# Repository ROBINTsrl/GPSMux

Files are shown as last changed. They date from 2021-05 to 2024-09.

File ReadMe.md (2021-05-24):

# GPSMux

This board and related firmware can be used to switch between two serial NMEA GPS feed based on fix status.
The resulting feed is transmitted over a third serial line with RS232 levels.
The board is designed around [Cypress](https://www.cypress.com/) PSoC CY8C27143.

PCB has been designed with [KiCAD](https://www.kicad.org/).

## Firmware

The project firmware requires Cypress [PSoC Designer 5.4](https://www.cypress.com/documentation/software-and-drivers/psoc-designer-54-sp1) to be compiled.

#

Live long and prosper!

That's all folks.

By[t]e{s} Weirdgyn

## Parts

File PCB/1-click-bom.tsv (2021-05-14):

References | Qty | Digikey | Manufacturer | Mouser | RS | mpn
C1, C2, C3, C4, C5, C6 | 6 | 478-5309-1-ND | AVX | 581-06035C104K4 | 698-3251 | 06035C104K4T2A
D1 | 1 | 475-3467-1-ND | OSRAM | 720-LYQ396P1Q236 | 778-1434 | LY Q396
P1 | 1 | WM7622CT-ND | Molex | 538-53261-0471 | 542-7113 | 53261-0471
P2 | 1 | WM7622CT-ND | Molex | 538-53261-0471 | 542-7113 | 53261-0471
P3 | 1 | WM7622CT-ND | Molex | 538-53261-0471 | 542-7113 | 53261-0471
P4 | 1 | WM7621CT-ND | Molex | 538-53261-0371 | 542-7107 | 53261-0371
R1 | 1 | 541-120HCT-ND | Vishay | 71-CRCW0603-120-E3 | 678-9718 | CRCW0603120RFKEA
R2, R3 | 2 | 541-4013-1-ND | Vishay | 71-CRCW06030000Z0EB | 678-9670 | CRCW06030000Z0EB
U1 | 1 | 428-1593-ND | Cypress | 727-CY8C27143-24PXI | 125-4170 | CY8C27143-24PXI
U2 | 1 | ADM3101EARQZ-REELCT-ND | Analog Devices | 584-ADM3101EARQZ | 709-7966 | ADM3101EARQZ

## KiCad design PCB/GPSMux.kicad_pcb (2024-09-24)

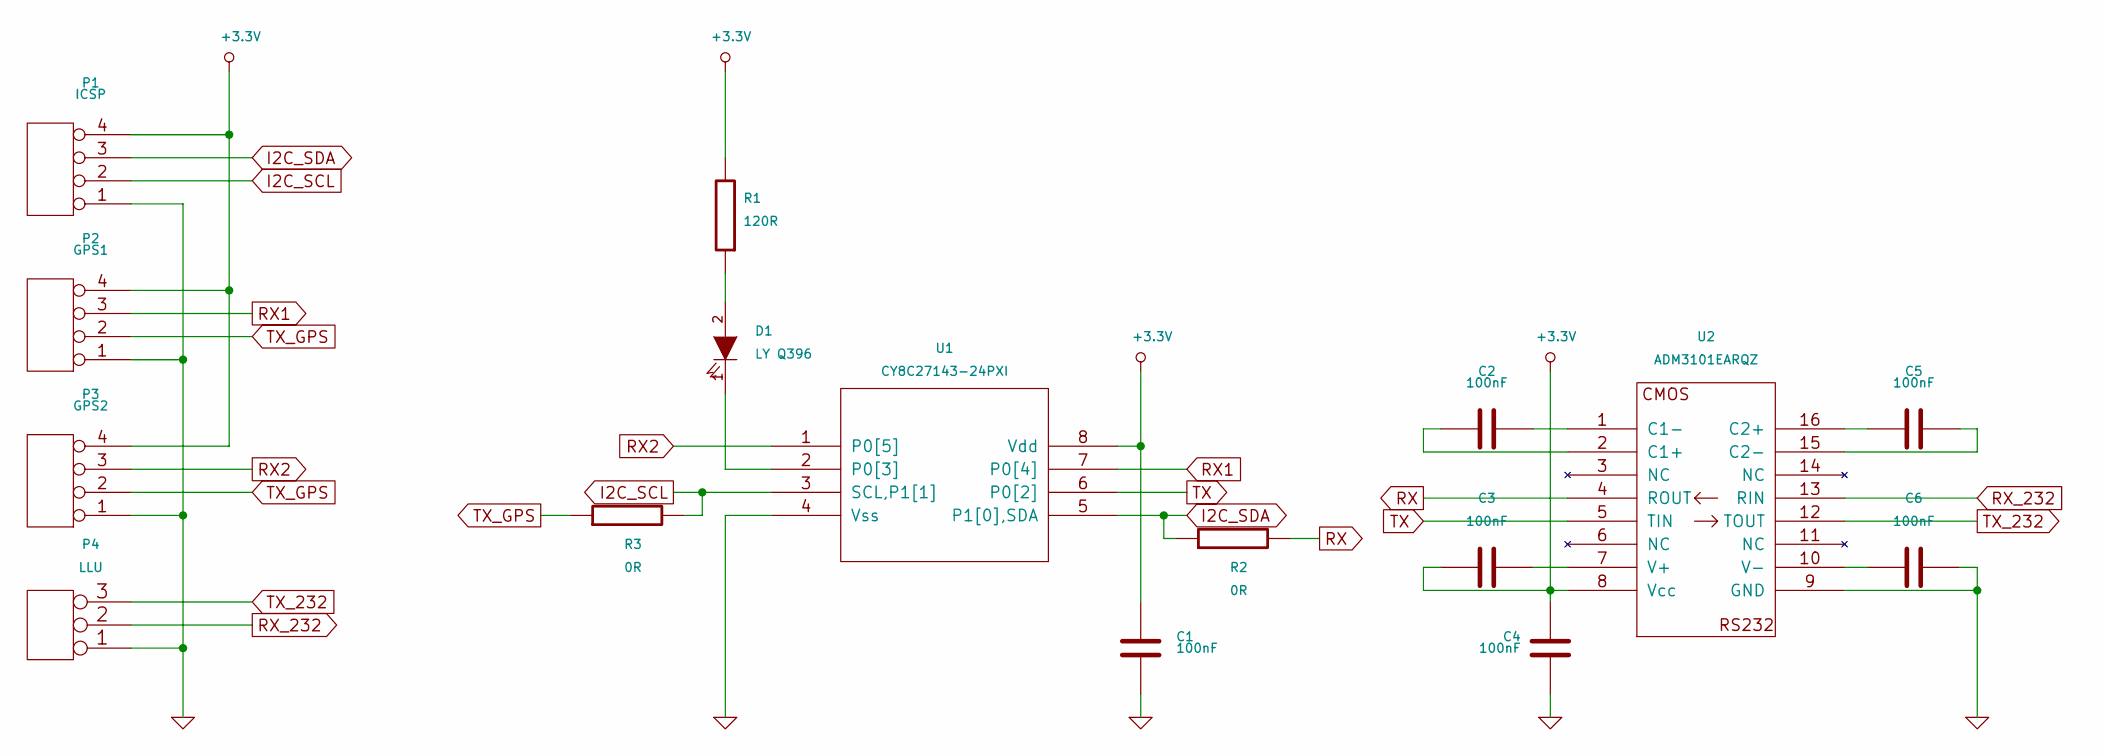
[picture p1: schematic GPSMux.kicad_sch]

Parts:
C1, C2, C3, C4, C5, C6: 100nF; C_0603; mpn 06035C104K4T2A; Digikey 478-5309-1-ND
D1: LY Q396; LED_0603_HandSoldering; mpn LY Q396; Digikey 475-3467-1-ND
P1: ICSP; 53261-0471; mpn 53261-0471; Digikey WM7622CT-ND
P2: GPS1; 53261-0471; mpn 53261-0471; Digikey WM7622CT-ND
P3: GPS2; 53261-0471; mpn 53261-0471; Digikey WM7622CT-ND
P4: LLU; 53261-0371; mpn 53261-0371; Digikey WM7621CT-ND
R1: 120R; R_0603_HandSoldering; mpn CRCW0603120RFKEA; Digikey 541-120HCT-ND
R2, R3: 0R; R_0603_HandSoldering; mpn CRCW06030000Z0EB; Digikey 541-4013-1-ND
U1: CY8C27143-24PXI; DIP-8_W10.16mm; mpn CY8C27143-24PXI; Digikey 428-1593-ND
U2: ADM3101EARQZ; QSOP16; mpn ADM3101EARQZ; Digikey ADM3101EARQZ-REELCT-ND

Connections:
+3.3V: C1.1, C3.2, C4.1, P1.4, P2.4, P3.4, R1.2, U1.8 (Vdd), U2.8 (Vcc)
GND: C1.2, C4.2, C6.1, P1.1, P2.1, P3.1, P4.1, U1.4 (Vss), U2.9 (GND)
I2C_SCL: P1.2, R3.2, U1.3 (SCL,P1[1])
I2C_SDA: P1.3, R2.1, U1.5 (P1[0],SDA)
unnamed: C2.1, U2.1 (C1-)
unnamed: C2.2, U2.2 (C1+)
unnamed: C3.1, U2.7 (V+)
unnamed: C5.1, U2.16 (C2+)
unnamed: C5.2, U2.15 (C2-)
unnamed: C6.2, U2.10 (V-)
unnamed: D1.1 (K), U1.2 (P0[3])
unnamed: D1.2 (A), R1.1
RX: R2.2, U2.4 (ROUT)
RX1: P2.3, U1.7 (P0[4])
RX2: P3.3, U1.1 (P0[5])
RX_232: P4.2 (PM), U2.13 (RIN)
TX: U1.6 (P0[2]), U2.5 (TIN)
TX_232: P4.3, U2.12 (TOUT)
TX_GPS: P2.2, P3.2, R3.1

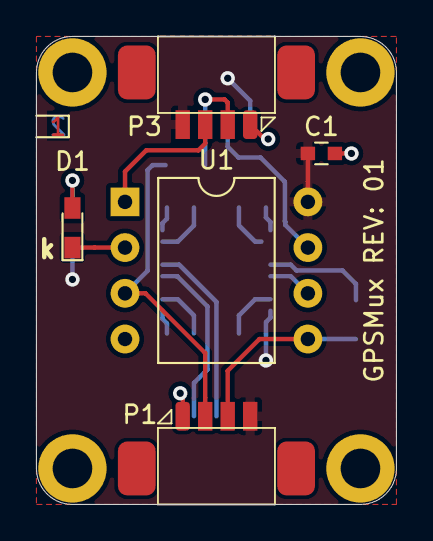
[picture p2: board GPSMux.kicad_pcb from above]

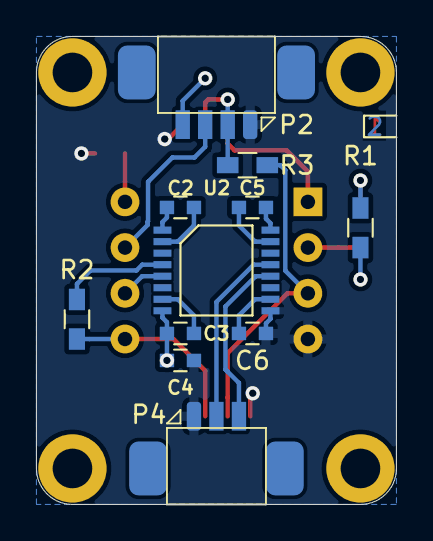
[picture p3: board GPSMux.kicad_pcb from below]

Board: 2 copper layers, 20.0 x 26.0 mm, 16 parts (11 on the bottom side), 19 nets.

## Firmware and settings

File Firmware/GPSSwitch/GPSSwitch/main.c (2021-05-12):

//----------------------------------------------------------------------------
// C main line
//----------------------------------------------------------------------------

#include <m8c.h>        // part specific constants and macros
#include "PSoCAPI.h"    // PSoC API definitions for all User Modules

#include "queue.h"

#define NO_FIX				0
#define FIX0				1
#define FIX1				2
#define FIX2				3

#define IDLE				0
#define	SENTENCE			1
#define SFIX				2

#define SoM					'$'
#define GGA_PREFIX			"GPGGA"

#define FIX_POSITION		5	// Six commas minus 1 due to parser structure
#define FIX_POSITION_MARK	','

typedef struct {
	BYTE fix_status;
	BYTE parse_status;
	BYTE idx;
} GPSStatus;

BOOL TX8_TX_Pending = FALSE;

GPSStatus gps1 = { NO_FIX, IDLE, 0 };
GPSStatus gps2 = { NO_FIX, IDLE, 0 };

Queue queue;

void parse(char c, GPSStatus* gps)
{
	// TODO: TODO add support for GPGSA sentence
	switch (gps->parse_status)
	{
		case IDLE:
			if (c == SoM) {
				gps->parse_status = SENTENCE;
				gps->idx = 0;
			}
			break;

		case SENTENCE:
			if ((gps->idx < (sizeof(GGA_PREFIX)-1)) && (c == GGA_PREFIX[gps->idx]))
				gps->idx++;
			else if (gps->idx == (sizeof (GGA_PREFIX)-1)) {
				gps->idx = 0;
				gps->parse_status = SFIX;
			}
			else
				gps->parse_status = IDLE;
			break;
		
		case SFIX:
			if ((gps->idx<FIX_POSITION) && (c == FIX_POSITION_MARK))
				gps->idx++;
			else if (gps->idx==FIX_POSITION) {
				gps->parse_status = IDLE;
				gps->fix_status = c - '0';
			}
			break;

		default :
			gps->parse_status = IDLE;
			break;
	}
}

void RX8_1_IRQ(void )
{
	static BYTE _bData;
	static BYTE _bStatus;
	
	_bStatus = RX8_1_bReadRxStatus();
	
	if ((_bStatus & RX8_1_RX_COMPLETE) && !(_bStatus & RX8_1_RX_ERROR))
	{
		_bData = RX8_1_bReadRxData();
		
		parse(_bData, &gps1);
		
		if (gps1.fix_status >= gps2.fix_status)	// Higher priority
			enqueue(&queue, _bData);
		else if ((gps1.fix_status == NO_FIX) && (gps2.fix_status == NO_FIX))	// Out GPS1 data if both GPSx are NOT FIXED
			enqueue(&queue, _bData);			
	}
}

void RX8_2_IRQ(void )
{
	static BYTE _bData;
	static BYTE _bStatus;
	
	_bStatus = RX8_2_bReadRxStatus();
	
	if ((_bStatus & RX8_2_RX_COMPLETE) && !(_bStatus & RX8_2_RX_ERROR))
	{
		_bData = RX8_2_bReadRxData();

		parse(_bData, &gps2);

		if (gps2.fix_status > gps1.fix_status)
			enqueue(&queue, _bData);
	}
}

void TX8_IRQ(void )
{
	TX8_TX_Pending = TRUE;
}

void main(void)
{
	BYTE _bData;
	
	initQueue(&queue);
	
	M8C_EnableGInt;
	
	TX8_EnableInt();
	TX8_Start(TX8_PARITY_NONE);
	
	RX8_1_EnableInt();
	RX8_1_Start(RX8_1_PARITY_NONE);

	RX8_2_EnableInt();
	RX8_2_Start(RX8_2_PARITY_NONE);
	
	TX8_CPutString("GPSSwitch\n\r");
	
	LED_FIX_Off();
	
	while (TRUE)
	{
		M8C_ClearWDT;
		
		if ( TX8_TX_Pending )
		{			
			if(dequeue(&queue, &_bData))
			{
				TX8_TX_Pending = FALSE;
				TX8_SendData(_bData);
			}
		}
		
		if ((gps1.fix_status > NO_FIX) || (gps2.fix_status > NO_FIX))
			LED_FIX_On();
		else 
			LED_FIX_Off();
	}
}

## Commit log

2021-05-12 Fist command
    [GPSMux-B_Cu.gbr, GPSMux-B_Mask.gbr, GPSMux-B_Paste.gbr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]
2021-05-12 Fix 3d components paths
    [GPSMux.kicad_pcb]
2021-05-12 Updated BOM, zone settings modified, components 3d updated
    [1-click-bom.csv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]
2021-05-13 Modified folders tree
    [1-click-bom.csv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]
2021-05-13 Update BOM
    Revert on .tsv
    [1-click-bom.csv, 1-click-bom.tsv]
2021-05-13 Updated BOM
    [1-click-bom.tsv, GPSMux.sch]
2021-05-14 Update BOM
    [1-click-bom.tsv, GPSMux.sch]
2024-09-24 Updated to kicad 8.0
    [GPSMux.kicad_pcb, GPSMux.kicad_sch, GPSMux.sch]
